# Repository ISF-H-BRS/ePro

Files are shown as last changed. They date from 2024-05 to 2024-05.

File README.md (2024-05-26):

# ePro: Secret Messages

## Introduction
ePro (short for entry-level project) was a series of introduction courses offered by Bonn-Rhein-Sieg University of Applied Sciences starting in 2010.

One of these courses, named "Secret Messages", aimed to give first-semester students a practical introduction to the field of data transmission, from the most low-level concepts, such as logical voltage levels, over bus systems like UART, SPI and I²C up to higher-level concepts, such as protocol stacks and data encryption.

This repository contains schematics, PCB layout and firmware for a circuit board originally developed during an internship project in the summer of 2010 to support this course beginning later that year. These devices, based on an ATmega32 microcontroller, can communicate over any of the three aforementioned interfaces and exchange messages using a very simple encryption scheme. All signals are exposed via pin headers for analysis by means of oscilloscope and/or bus sniffer.

<p align="center">
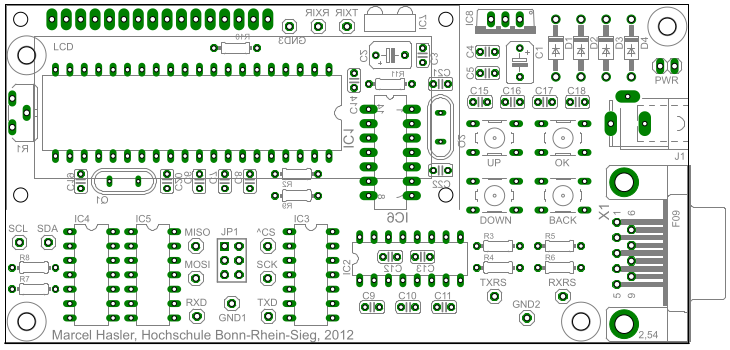
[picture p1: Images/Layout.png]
  
</p>

The message to be transmitted can be selected from a built-in database of famous quotations through a pin-protected administration menu where also the encryption key can be set. The goal of the project was for every team to analyze the data transmitted over the chosen interface, decipher the message and document their findings along the way.

Unfortunately the ePro courses were canceled with the introduction of a new curriculum some years ago. This repository is provided in the hope that the circuit boards developed back in 2010 might still find some use in similar academic projects in the future.

<p align="center">
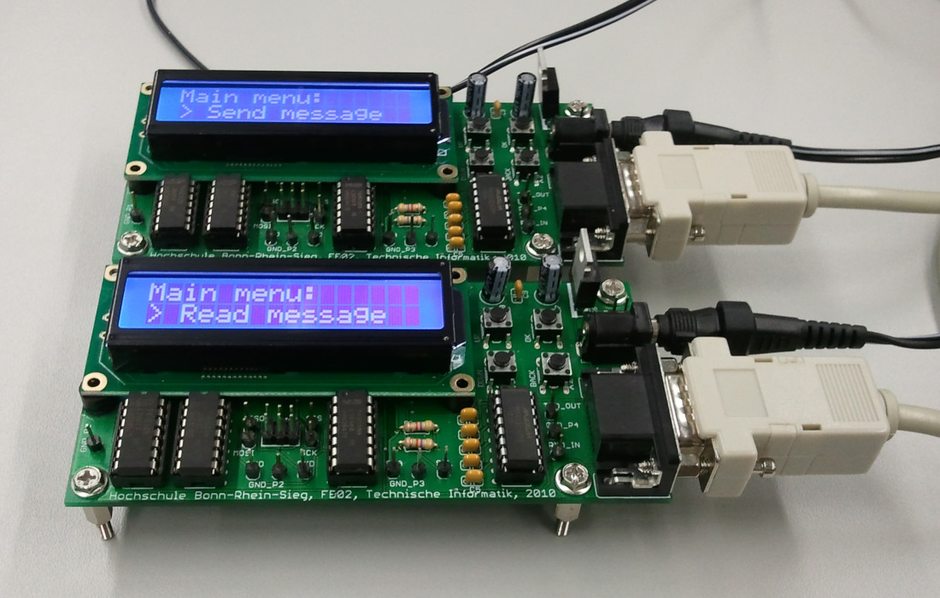
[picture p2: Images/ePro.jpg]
  
</p>

## License
The source code for the firmware is licensed under the terms of the GNU General Public License (GPL). The schematics and layout files are licensed under the terms of the Creative Commons Attribution-ShareAlike International Public License (CC BY-SA). See COPYING in the respective subdirectories for details.

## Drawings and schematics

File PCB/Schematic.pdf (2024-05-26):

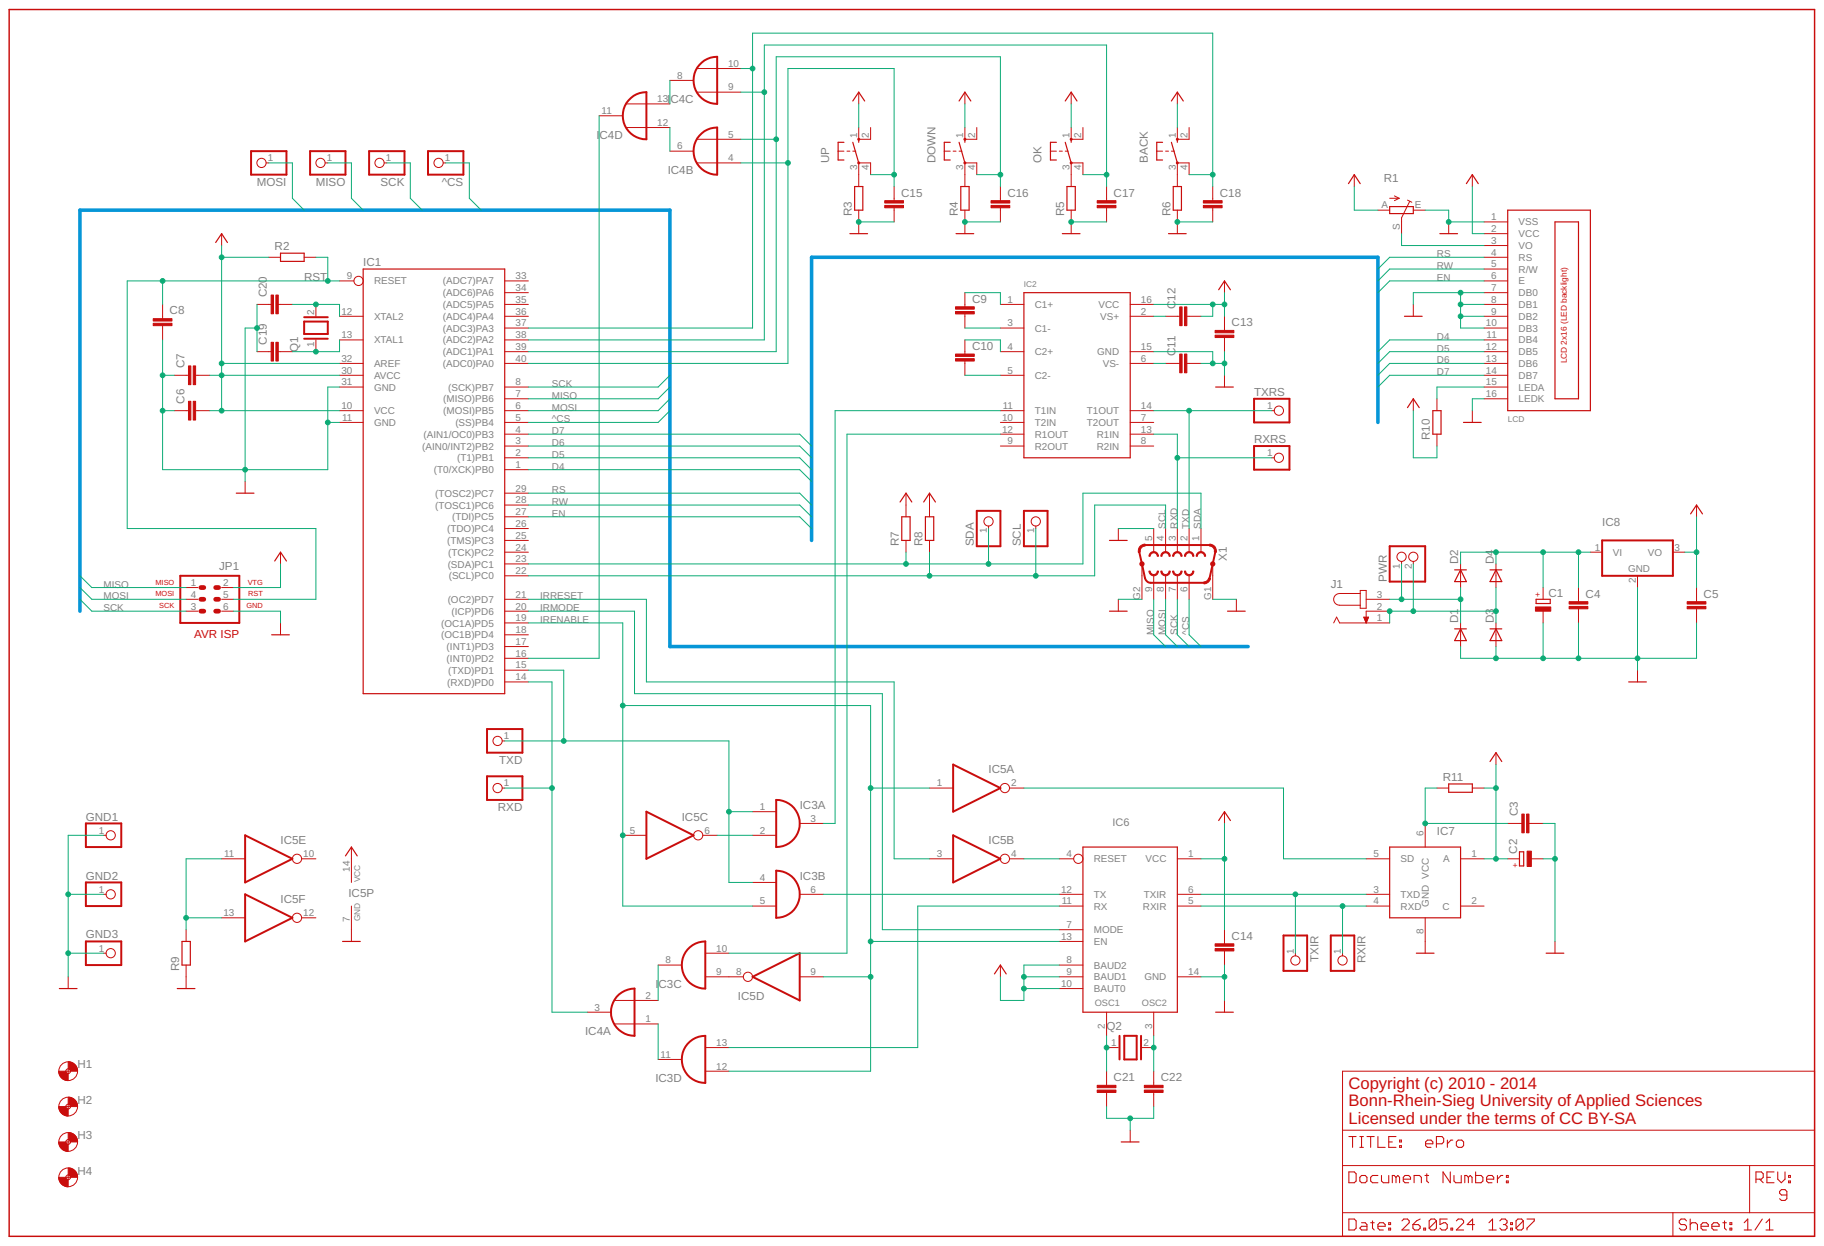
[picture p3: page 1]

2 D5
1 D4

29 RS
28 RW
27 EN
26

19 IRENABLE
18

Copyright (c) 2010 - 2014
Bonn-Rhein-Sieg University of Applied Sciences Licensed under the terms of CC BY-SA

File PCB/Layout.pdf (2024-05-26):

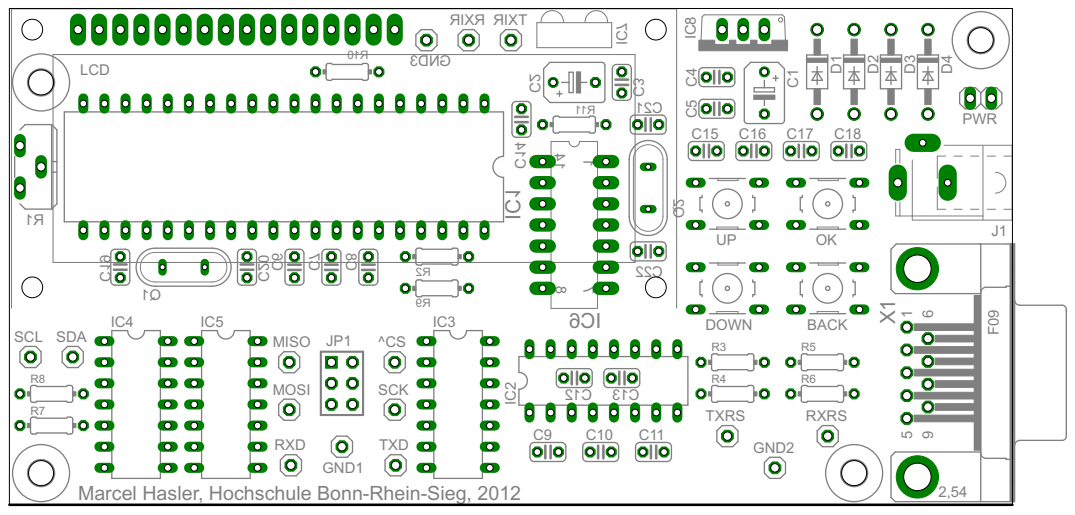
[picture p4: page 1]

Marcel Hasler, Hochschule Bonn-Rhein-Sieg, 2012

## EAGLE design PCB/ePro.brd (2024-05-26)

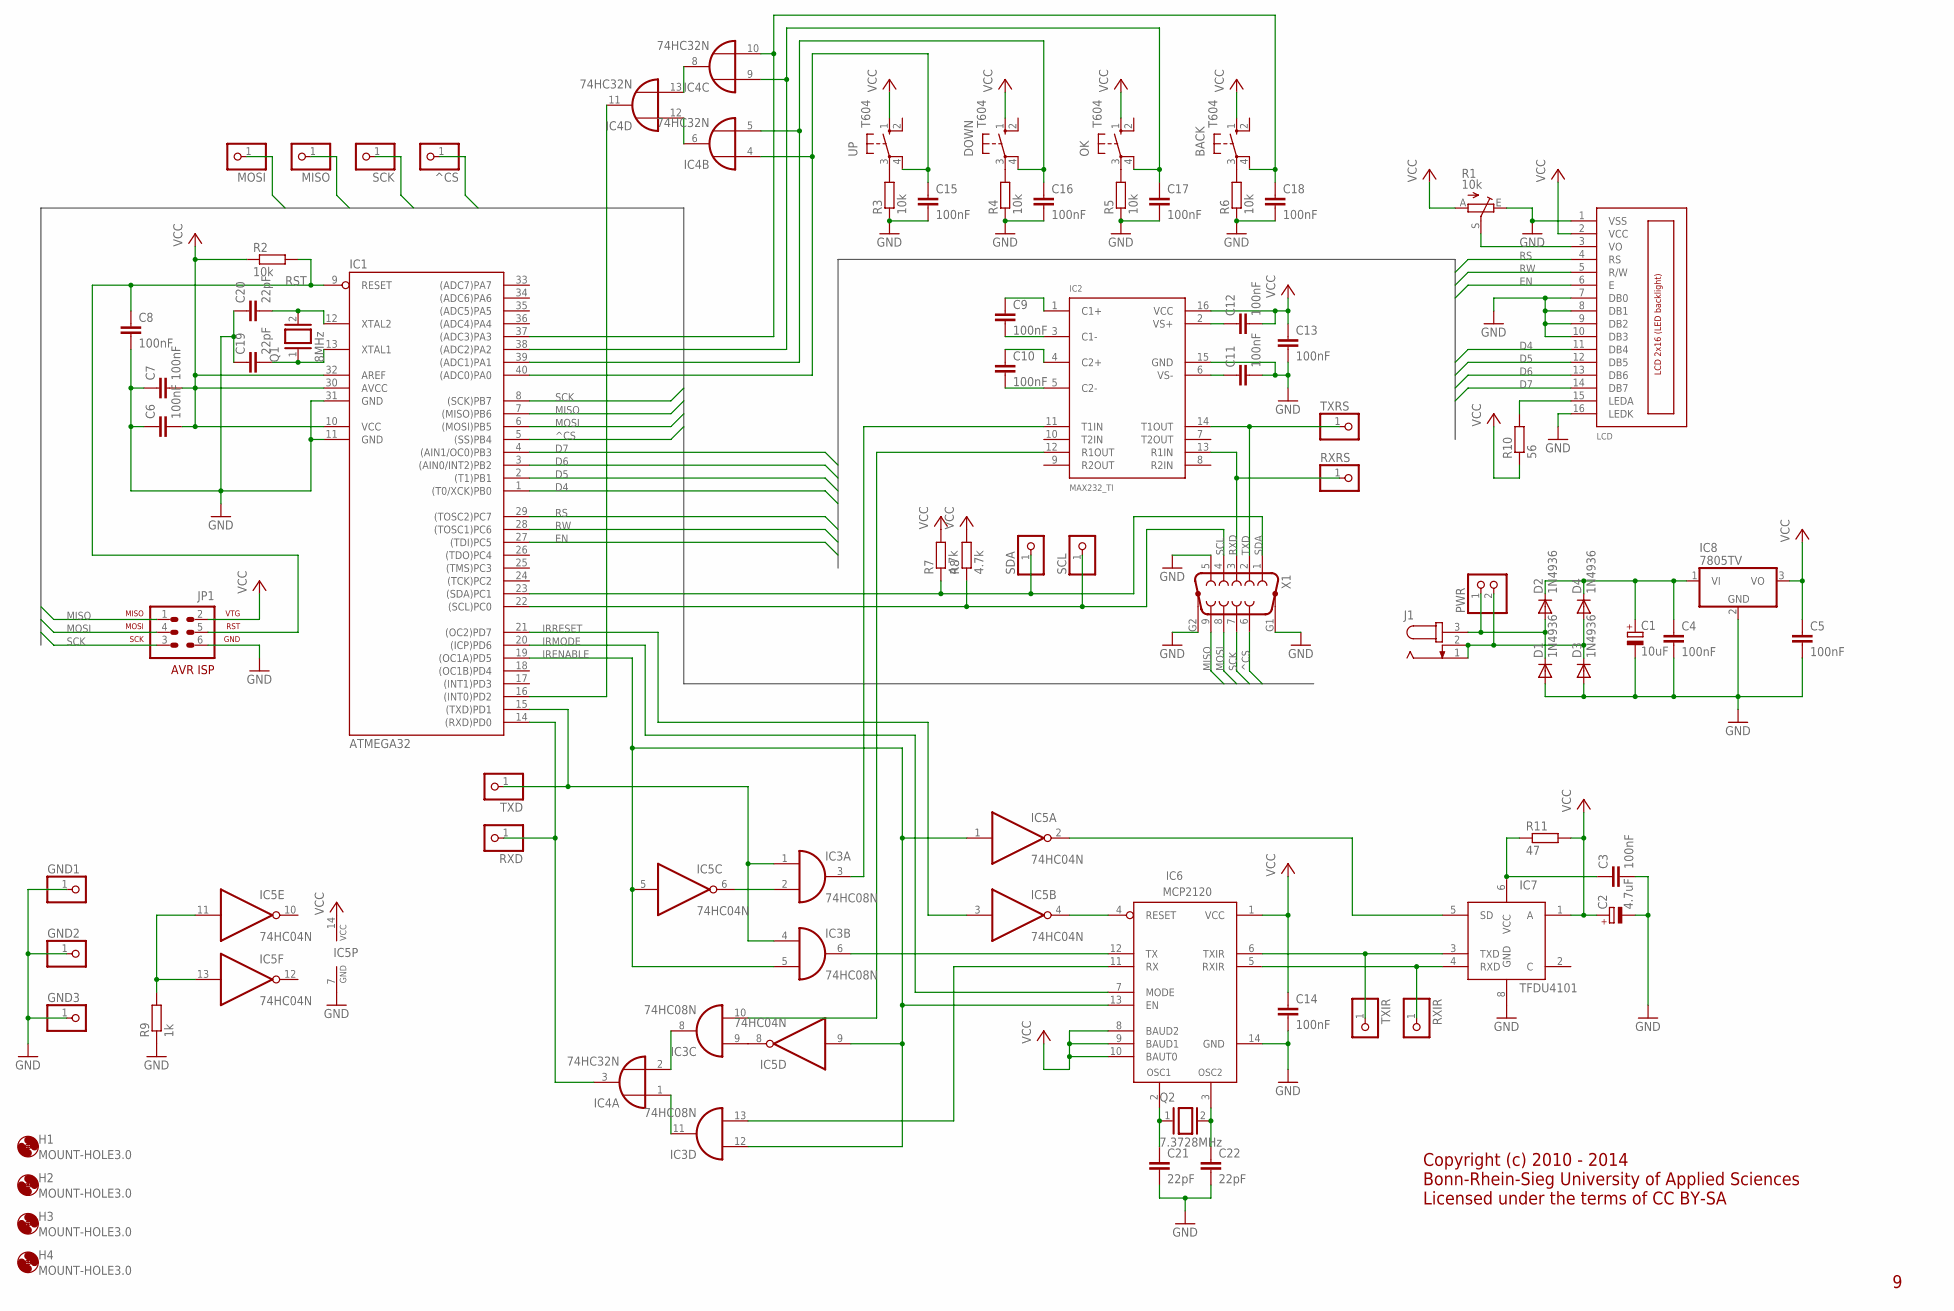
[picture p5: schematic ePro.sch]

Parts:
BACK: T604; T602/604
C1: 10uF; B45181B
C2: 4.7uF; B45181B
C3, C4, C5, C6, C7, C8, C9, C10, C11, C12, C13, C14, C15, C16, C17, C18: 100nF; C025-024X044
C19, C20, C21, C22: 22pF; C025-024X044
D1, D2, D3, D4: 1N4936; DO41-10
DOWN: T604; T602/604
GND1, GND2, GND3: PINHD-1X1; 1X01
H1, H2, H3, H4: MOUNT-HOLE3.0; 3,0
IC1: ATMEGA32; DIL40
IC2: MAX232_TI; DIL16
IC3: 74HC08N; DIL14
IC4: 74HC32N; DIL14
IC5: 74HC04N; DIL14
IC6: MCP2120; DIL14
IC7: TFDU4101; U
IC8: 7805TV; TO220V
J1: JACK-PLUG1; SPC4078
JP1: AVR-ISP-6
LCD: LCD_2X16_SIL; HY-1602F
MISO: PINHD-1X1; 1X01
MOSI: PINHD-1X1; 1X01
OK: T604; T602/604
PWR: PINHD-1X2; 1X02
Q1: 8MHz; QS
Q2: 7.3728MHz; QS
R1: 10k; PT-10S
R2, R3, R4, R5, R6: 10k; 0204/7
R7, R8: 4.7k; 0204/7
R9: 1k; 0204/7
R10: 56; 0204/7
R11: 47; 0204/7
RXD: PINHD-1X1; 1X01
RXIR: PINHD-1X1; 1X01
RXRS: PINHD-1X1; 1X01
SCK: PINHD-1X1; 1X01
SCL: PINHD-1X1; 1X01
SDA: PINHD-1X1; 1X01
TXD: PINHD-1X1; 1X01
TXIR: PINHD-1X1; 1X01
TXRS: PINHD-1X1; 1X01
UP: T604; T602/604
X1: F09HP
^CS: PINHD-1X1; 1X01

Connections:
D4: IC1.1 ((T0/XCK)PB0), LCD.11 (DB4)
D5: IC1.2 ((T1)PB1), LCD.12 (DB5)
D6: IC1.3 ((AIN0/INT2)PB2), LCD.13 (DB6)
D7: IC1.4 ((AIN1/OC0)PB3), LCD.14 (DB7)
EN: IC1.27 ((TDI)PC5), LCD.6 (E)
GND: C1.-, C2.-, C3.2, C4.2, C5.2, C6.1, C7.1, C8.2, C11.2, C13.2, C14.2, C15.2, C16.2, C17.2, C18.2, C19.1, C20.1, C21.2, C22.2, D1.A, D3.A, GND1.1, GND2.1, GND3.1, IC1.11 (GND), IC1.31 (GND), IC2.15 (GND), IC3.7 (GND), IC4.7 (GND), IC5.7 (GND), IC6.14 (GND), IC7.8 (GND), IC8.2 (GND), JP1.6, LCD.1 (VSS), LCD.7 (DB0), LCD.8 (DB1), LCD.9 (DB2), LCD.10 (DB3), LCD.16 (LEDK), R1.E, R3.1, R4.1, R5.1, R6.1, R9.1, X1.5, X1.G1, X1.G2
IRENABLE: IC1.19 ((OC1A)PD5), IC3.5 (I1), IC3.12 (I0), IC5.1 (I), IC5.5 (I), IC5.9 (I), IC6.13 (EN)
IRMODE: IC1.20 ((ICP)PD6), IC6.7 (MODE)
IRRESET: IC1.21 ((OC2)PD7), IC5.3 (I)
IRSHUTDOWN: IC5.2 (O), IC7.5 (SD)
MISO: IC1.7 ((MISO)PB6), JP1.1, MISO.1, X1.9
MOSI: IC1.6 ((MOSI)PB5), JP1.4, MOSI.1, X1.8
unnamed: IC1.15 ((TXD)PD1), IC3.1 (I0), IC3.4 (I0), TXD.1
unnamed: C15.1, IC1.40 ((ADC0)PA0), IC4.4 (I0), UP.4
unnamed: IC3.2 (I1), IC5.6 (O)
unnamed: IC4.6 (O), IC4.12 (I0)
unnamed: IC6.5 (RXIR), IC7.4 (RXD), RXIR.1
unnamed: C20.2, IC1.12 (XTAL2), Q1.2
unnamed: IC3.6 (O), IC6.12 (TX)
unnamed: C21.1, IC6.2 (OSC1), Q2.1
unnamed: IC6.6 (TXIR), IC7.3 (TXD), TXIR.1
unnamed: C16.1, DOWN.4, IC1.39 ((ADC1)PA1), IC4.5 (I1)
unnamed: C17.1, IC1.38 ((ADC2)PA2), IC4.9 (I0), OK.4
unnamed: IC2.12 (R1OUT), IC3.10 (I1)
unnamed: C11.1, IC2.6 (VS-)
unnamed: C3.1, IC7.6 (VCC), R11.1
unnamed: LCD.3 (VO), R1.S
unnamed: IC5.4 (O), IC6.4 (RESET)
unnamed: C22.1, IC6.3 (OSC2), Q2.2
unnamed: C10.2, IC2.5 (C2-)
unnamed: C19.2, IC1.13 (XTAL1), Q1.1
unnamed: IC3.13 (I1), IC6.11 (RX)
unnamed: IC3.9 (I0), IC5.8 (O)
unnamed: C1.+, C4.1, D2.C, D4.C, IC8.1 (VI)
unnamed: IC4.8 (O), IC4.13 (I1)
unnamed: C10.1, IC2.4 (C2+)
unnamed: LCD.15 (LEDA), R10.2
unnamed: IC3.8 (O), IC4.2 (I1)
unnamed: C9.2, IC2.3 (C1-)
unnamed: IC3.11 (O), IC4.1 (I0)
unnamed: IC1.14 ((RXD)PD0), IC4.3 (O), RXD.1
unnamed: C9.1, IC2.1 (C1+)
unnamed: C12.1, IC2.2 (VS+)
unnamed: D3.C, D4.A, J1.1, J1.2, PWR.2
unnamed: D1.C, D2.A, J1.3, PWR.1
unnamed: BACK.3, R6.2
unnamed: IC1.16 ((INT0)PD2), IC4.11 (O)
unnamed: BACK.4, C18.1, IC1.37 ((ADC3)PA3), IC4.10 (I1)
unnamed: IC2.11 (T1IN), IC3.3 (O)
unnamed: OK.3, R5.2
unnamed: DOWN.3, R4.2
unnamed: R3.2, UP.3
unnamed: IC5.11 (I), IC5.13 (I), R9.2
RS: IC1.29 ((TOSC2)PC7), LCD.4 (RS)
RST: C8.1, IC1.9 (RESET), JP1.5, R2.2
RW: IC1.28 ((TOSC1)PC6), LCD.5 (R/W)
RXD: IC2.13 (R1IN), RXRS.1, X1.3
SCK: IC1.8 ((SCK)PB7), JP1.3, SCK.1, X1.7
SCL: IC1.22 ((SCL)PC0), R8.1, SCL.1, X1.4
SDA: IC1.23 ((SDA)PC1), R7.1, SDA.1, X1.1
TXD: IC2.14 (T1OUT), TXRS.1, X1.2
VCC: BACK.1, C2.+, C5.1, C6.2, C7.2, C12.2, C13.1, C14.1, DOWN.1, IC1.10 (VCC), IC1.30 (AVCC), IC1.32 (AREF), IC2.16 (VCC), IC3.14 (VCC), IC4.14 (VCC), IC5.14 (VCC), IC6.1 (VCC), IC6.8 (BAUD2), IC6.9 (BAUD1), IC6.10 (BAUT0), IC7.1 (A), IC8.3 (VO), JP1.2, LCD.2 (VCC), OK.1, R1.A, R2.1, R7.2, R8.2, R10.1, R11.2, UP.1
^CS: IC1.5 ((SS)PB4), X1.6, ^CS.1

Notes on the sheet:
Copyright (c) 2010 - 2014 Bonn-Rhein-Sieg University of Applied Sciences Licensed under the terms of CC BY-SA

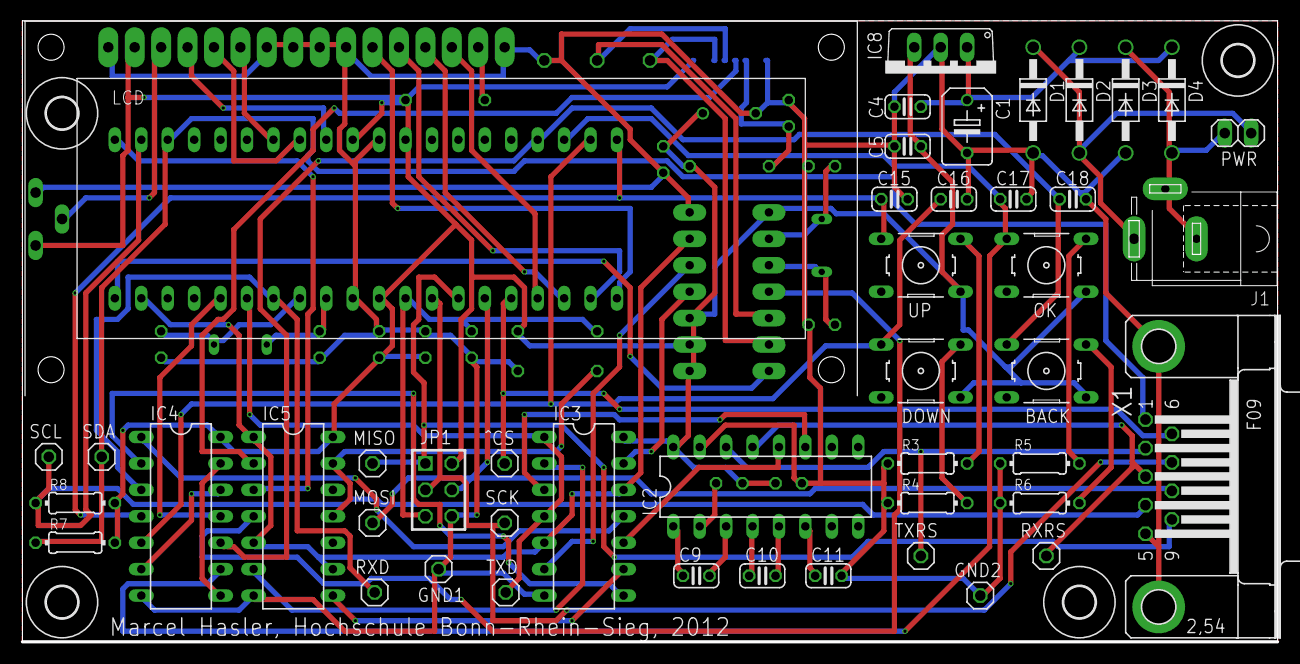
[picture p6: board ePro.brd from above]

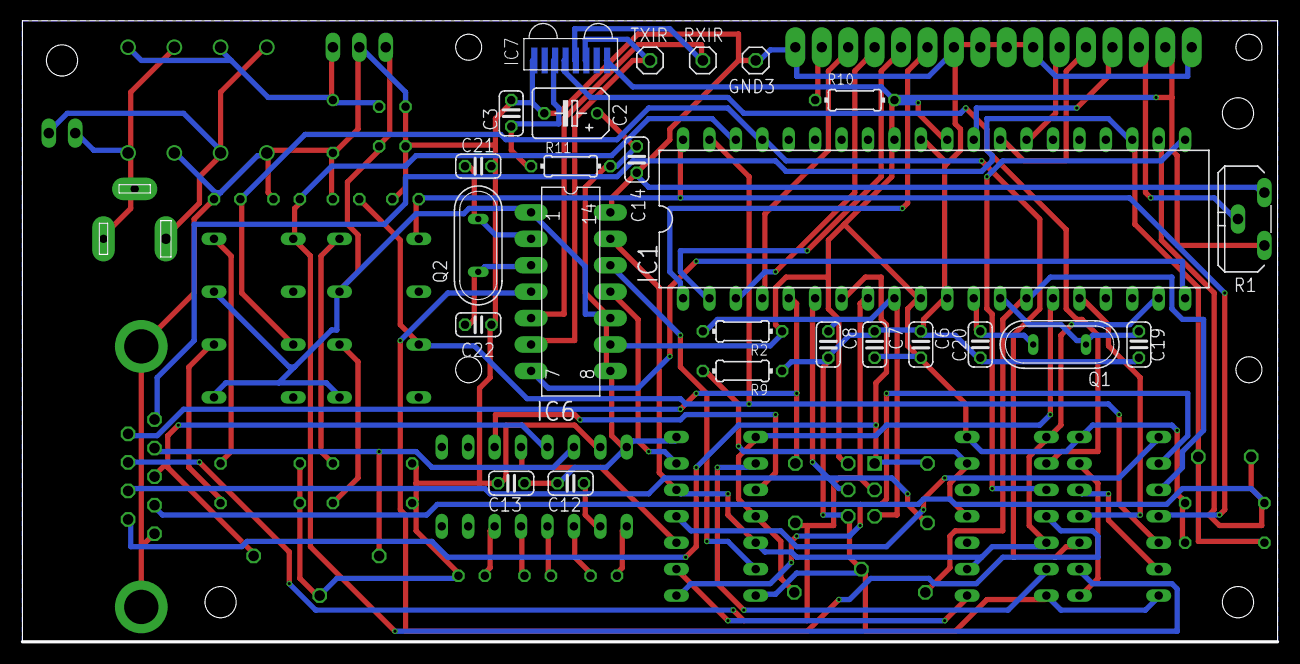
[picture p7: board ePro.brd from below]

Board: 2 copper layers, 120.7 x 59.7 mm, 75 parts (25 on the bottom side), 63 nets.

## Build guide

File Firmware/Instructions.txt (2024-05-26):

Compilation and Installation of the ePro Firmware
-------------------------------------------------

The ePro firmware uses a CMake project file for compilation and installation. It is
intended for use on Linux/Unix and assumes an Atmel AVR ISP mkII as programmer.

The following software components are required:
* CMake >=3.5
* GNU Make
* GNU AVR Toolchain (avr-binutils, avr-gcc, avr-libc)
* Python 3.x
* AVRDUDE

Run 'mkdir build && cd build && cmake -DCMAKE_TOOLCHAIN_FILE=../AVRToolchain.cmake ..'
to generate a Makefile, then run 'make' to compile the firmware.

When programming a device for the first time, the correct fuse bits need to be set by
running 'make fuses'.

To upload the compiled program to the ePro device, simply run 'make program'.

Access to the programmer usually requires root permissions. In order to be able to program
the device as a normal user, we can define a custom udev rule. To do so, create a new rule
file (e.g. /etc/udev/rules.d/10-avrdude.rules) with the following content:

# Atmel AVR ISP mkII
SUBSYSTEM=="usb", ATTR{idVendor}=="03eb", ATTR{idProduct}=="2104", GROUP="users", MODE="0660"

To apply the new rule immediately, run 'udevadm control --reload', then reconnect the programmer.

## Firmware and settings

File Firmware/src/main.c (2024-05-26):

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
#include "config.h"
#include "epro.h"
#include "lcd.h"
#include "messagetable.h"
#include "settings.h"

#include <stdlib.h>
#include <string.h>


// Forward declarations
static void send(const message_t *message);
static void read(void);


// Settings
static settings_t current_settings;


// Result strings
static const char result_string0[] PROGMEM = "Success!";
static const char result_string1[] PROGMEM = "Failed!";
static const char result_string2[] PROGMEM = "Aborted!";
static const char result_string3[] PROGMEM = "Timeout!";
static const char result_string4[] PROGMEM = "Error!";
static PGM_P const result_strings[RESULT_COUNT] =
{
    result_string0,
    result_string1,
    result_string2,
    result_string3,
    result_string4
};


// Main menu
static void send_test(void);
static void read_test(void);

static void send_message(void);
static void read_message(void);

static void show_settings(void);

static const menu_entry_t main_menu_entries[] =
{
    { "Send test",    send_test     },
    { "Read test",    read_test     },
    { "Send message", send_message  },
    { "Read message", read_message  },
    { "Settings",     show_settings }
};

MENU_INIT(main_menu, "Main menu:", 5, main_menu_entries, false);


// Function definitions
void send(const message_t *message)
{
    for (uint8_t i = 0; i < EPRO_MESSAGE_COUNT; ++i)
    {
        lcd_clear();
        lcd_printf_PSTR(0, "Sending %02d/%02d...", i+1, EPRO_MESSAGE_COUNT);

        result_t result = epro_send_message(message);

        lcd_printf_P(1, result_strings[result]);
        if (result == RESULT_ABORTED || epro_wait_ms(1000) == RESULT_ABORTED)
        {
            lcd_printf_P(1, result_strings[RESULT_ABORTED]);
            epro_delay_ms(1000);
            return;
        }
    }
}


void read()
{
    while (1)
    {
        lcd_clear();
        lcd_printf_PSTR(0, "Waiting...");

        message_t message;
        result_t result = epro_read_message(&message);

        if (current_settings.debug && result == RESULT_SUCCESS)
        {
            char* msg = message_get_string(&message);

            lcd_printf_PSTR(0, "Message:");
            lcd_printf_PSTR(1, "%s", msg);

            free(msg);
        }
        else
            lcd_printf_P(1, result_strings[result]);

        if (result == RESULT_SUCCESS)
            message_free(&message);

        if (result == RESULT_ABORTED || epro_wait_ms(800) == RESULT_ABORTED)
        {
            lcd_printf_P(1, result_strings[RESULT_ABORTED]);
            epro_delay_ms(1000);
            return;
        }
    }
}


void send_test()
{
    epro_set_bitrate_hint(BITRATE_HINT_SLOW_ABERRANT);

    char *message = malloc(EPRO_LCD_WIDTH + 1);
    memcpy(message, current_settings.test_message, EPRO_LCD_WIDTH);
    message[EPRO_LCD_WIDTH] = '\0';

    message_t msg;
    message_init(&msg, message, 0);
    free(message);
    send(&msg);
    message_free(&msg);
}


void read_test()
{
    epro_set_bitrate_hint(BITRATE_HINT_SLOW_ABERRANT);
    read();
}


void send_message()
{
    epro_set_bitrate_hint(BITRATE_HINT_SLOW_REGULAR);

    char *message = message_table_read_at(current_settings.message_index);

    message_t msg;
    message_init(&msg, message, current_settings.message_key);
    free(message);
    send(&msg);
    message_free(&msg);
}


void read_message()
{
    epro_set_bitrate_hint(BITRATE_HINT_SLOW_REGULAR);
    read();
}


void show_settings()
{
    settings_process_menu(&current_settings);
}


int main(void)
{
    // Load settings from EEPROM & initialize ePro library
    settings_load(&current_settings);
    epro_initialize(current_settings.interface_index);

    // Print info
    lcd_printf_PSTR(0, "ePro Firmware");
    lcd_printf_PSTR(1, "Version %s", EPRO_VERSION_STRING);
    epro_delay_ms(2000);

#if EPRO_DEVICE_LOCK_ENABLED
    if (current_settings.locked)
    {
        lcd_clear();
        lcd_printf_PSTR(0, "Device locked!");
        while (1);
    }
#endif

    // Start processing
    while (1)
        epro_process_menu(&main_menu);

    return 0;
}

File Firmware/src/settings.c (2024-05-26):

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
#include "epro.h"
#include "lcd.h"
#include "messagetable.h"
#include "scrolltext.h"
#include "settings.h"
#include "timer.h"

#include <avr/eeprom.h>

#include <stdbool.h>
#include <stdlib.h>
#include <string.h>


// EEPROM addresses
static uint8_t eep_interface_index EEMEM = EPRO_DEFAULT_INTERFACE_INDEX;
static uint8_t eep_test_message[EPRO_LCD_WIDTH] EEMEM = EPRO_DEFAULT_TEST_MESSAGE;
static uint16_t eep_message_index EEMEM = EPRO_DEFAULT_MESSAGE_INDEX;
static uint8_t eep_message_key[EPRO_BLOCK_LENGTH] EEMEM = EPRO_DEFAULT_MESSAGE_KEY;
static uint8_t eep_debug EEMEM = EPRO_DEFAULT_DEBUG ? 1 : 0;
static uint8_t eep_pin[EPRO_PIN_LENGTH] EEMEM = EPRO_DEFAULT_PIN;

#if EPRO_DEVICE_LOCK_ENABLED
static uint8_t eep_locked EEMEM = 0;
#endif


// Write/read single values to/from EEPROM
static void _settings_write_interface_index(uint8_t index);
static void _settings_read_interface_index(uint8_t *index);

static void _settings_write_message_index(uint16_t index);
static void _settings_read_message_index(uint16_t *index);

static void _settings_write_test_message(const uint8_t *message);
static void _settings_read_test_message(uint8_t *message);

static void _settings_write_message_key(const uint8_t *key);
static void _settings_read_message_key(uint8_t *key);

static void _settings_write_debug(bool debug);
static void _settings_read_debug(bool *debug);

static void _settings_write_pin(const uint8_t *pin);
static void _settings_read_pin(uint8_t *pin);

#if EPRO_DEVICE_LOCK_ENABLED
static void _settings_write_locked(bool locked);
static void _settings_read_locked(bool *locked);
#endif


// Helper
static bool _settings_check_pin(void);


// Interface menu
static void _settings_select_rs232(void);
static void _settings_select_irda(void);
static void _settings_select_spi(void);
static void _settings_select_i2c(void);

static const menu_entry_t interface_menu_entries[] =
{
    { "RS-232", _settings_select_rs232 },
    { "IrDA",   _settings_select_irda  },
    { "SPI",    _settings_select_spi   },
    { "I2C",    _settings_select_i2c   }
};

MENU_INIT(interface_menu, "Select iface:", 4, interface_menu_entries, true);


// Admin menu
static void _settings_select_message(void);
static void _settings_set_test_message(void);
static void _settings_set_key(void);
static void _settings_toggle_debug(void);
static void _settings_change_pin(void);

static const menu_entry_t admin_menu_entries[] =
{
    { "Select message", _settings_select_message   },
    { "Set test msg",   _settings_set_test_message },
    { "Set key",        _settings_set_key          },
    { "Toggle debug",   _settings_toggle_debug     },
    { "Change PIN",     _settings_change_pin       }
};

MENU_INIT(admin_menu, "Administration:", 5, admin_menu_entries, false);


// Settings menu
static void _settings_select_interface(void);
static void _settings_show_admin_menu(void);

static const menu_entry_t settings_menu_entries[] =
{
    { "Select iface",   _settings_select_interface },
    { "Administration", _settings_show_admin_menu  }
};

MENU_INIT(settings_menu, "Settings:", 2, settings_menu_entries, false);


void settings_save(const settings_t *settings)
{
    _settings_write_interface_index(settings->interface_index);
    _settings_write_message_index(settings->message_index);
    _settings_write_test_message(settings->test_message);
    _settings_write_message_key(settings->message_key);
    _settings_write_debug(settings->debug);

#if EPRO_DEVICE_LOCK_ENABLED
    _settings_write_locked(settings->locked);
#endif
}


void settings_load(settings_t *settings)
{
    _settings_read_interface_index(&settings->interface_index);
    _settings_read_message_index(&settings->message_index);
    _settings_read_test_message(settings->test_message);
    _settings_read_message_key(settings->message_key);
    _settings_read_debug(&settings->debug);

#if EPRO_DEVICE_LOCK_ENABLED
    _settings_read_locked(&settings->locked);
#endif
}


void settings_process_menu(settings_t *settings)
{
    epro_process_menu(&settings_menu);
    if (settings)
        settings_load(settings);
}


void _settings_write_interface_index(uint8_t index)
{
    eeprom_write_byte(&eep_interface_index, index);
}


void _settings_read_interface_index(uint8_t *index)
{
    *index = eeprom_read_byte(&eep_interface_index);
    if (*index == 0xff)
        *index = 0;
}


void _settings_write_message_index(uint16_t index)
{
    eeprom_write_word(&eep_message_index, index);
}


void _settings_read_message_index(uint16_t *index)
{
    *index = eeprom_read_word(&eep_message_index);
    if (*index == 0xffff)
        *index = 0;
}


void _settings_write_test_message(const uint8_t *message)
{
    eeprom_write_block(message, eep_test_message, EPRO_LCD_WIDTH);
}


void _settings_read_test_message(uint8_t *message)
{
    eeprom_read_block(message, eep_test_message, EPRO_LCD_WIDTH);
}


void _settings_write_message_key(const uint8_t *key)
{
    eeprom_write_block(key, eep_message_key, EPRO_BLOCK_LENGTH);
}
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

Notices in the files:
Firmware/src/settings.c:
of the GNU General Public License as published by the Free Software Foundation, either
